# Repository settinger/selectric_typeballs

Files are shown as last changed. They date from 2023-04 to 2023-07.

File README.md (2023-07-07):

# How to make your own Selectric Typeballs

## March 31, 2023

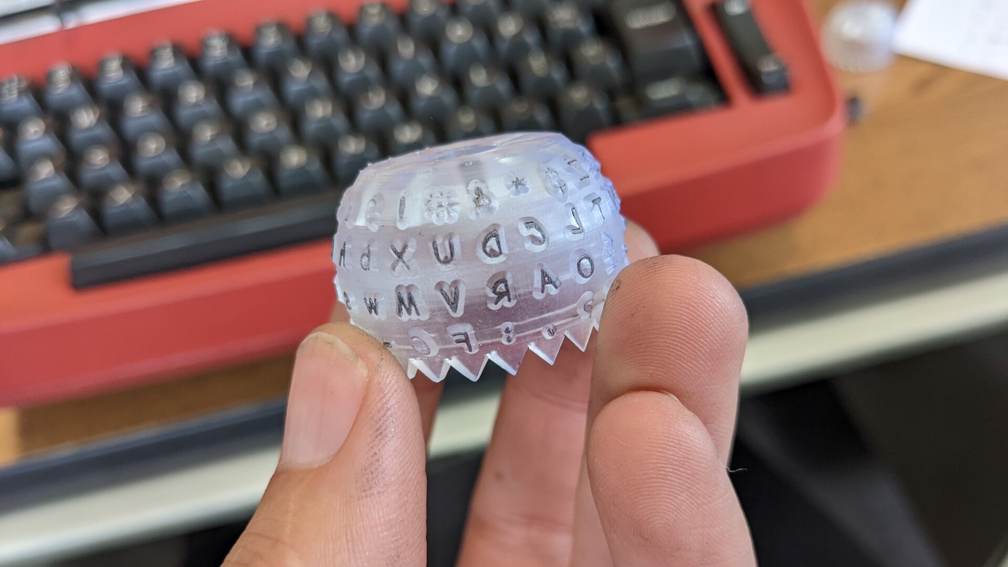
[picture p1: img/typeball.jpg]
A 3D printed typeball for the IBM Selectric. The font is Comic Sans. There is ink on most of the letters.

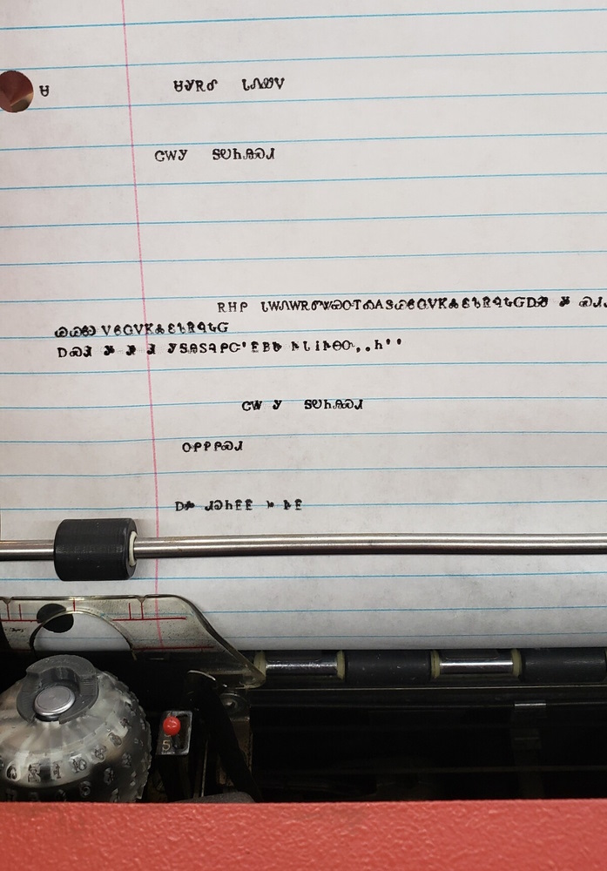
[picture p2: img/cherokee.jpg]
A sheet of lined paper in a typewriter with several lines of Cherokee text; the 3d printed typeball that made the text is visible in the lower left.


# Update: July 7 2023: YOU PROBABLY SHOULDN'T PRINT THIS!

Update, July 7 2023: [Dave Hayden](https://selectricrescue.org/) took the resin-printed typeball concept and [improved on it greatly](https://selectricrescue.org/balls/SelectricElement88.scad). I'm extremely grateful that he took on all the hard work of iteratively going through and dialing in the perfect values to make a functional ball, and I'm pleased to think I contributed in some way to his achievements.

The original README continues below.

-----------------------------------------

The [IBM Selectric typewriter](https://www.ibm.com/ibm/history/ibm100/us/en/icons/selectric/) uses an instantly-recognizable "ball" of type instead of a fanned-out array of arms like a conventional typewriter. These typeballs could be swapped out, meaning you could easily write documents with different fonts, font sizes, special characters, or different writing systems altogether.

IBM and some other vendors made lots of different typeballs, but most of them are 40-50 years old and no one has been making new typeballs for a long time. 3D printing is a natural fit for making new typeballs, but most printers still don't have the ability to produce the sharp details necessary on a sufficiently-resilient material. So it's understandable that no one made a really functional 3D-printable typeball. Until now, that is!

## Warning
Please keep in mind that the spindle that the typeball sits on is fragile. Do not force a typeball onto the spindle if it does not fit, and do not attempt to salvage a print by shaving it down. The typeball can become stuck on the delicate spindle, damaging your vintage typewriter. Similarly, do not use a typeball if it is too loose and cannot be attached securely. It could fly off and damage its surroundings.

You may wish to use a small amount of sewing machine oil on the inside of your print, to help it as it spins, and to catch any resin dust that is created by the printed ball rubbing against the spindle mount.

Any damage incurred through the use of this software and its resulting typeballs are not our liability.

## How to use the code
Things you need before getting started:
* OpenSCAD
* A Python installation with the [pymeshlab](https://pypi.org/project/pymeshlab/) package

1. Open `oneletter.scad` and change lines 11 and 12, the ones that specify the font height (in millimeters) and the font name/style for OpenSCAD to use.
1. Open `selectric_generator.py` and change line 5, the one that says `PATH TO OPENSCAD = r"{something}"` so that it points to your installation of `openscad.com` (not `openscad.exe`! They are in the same folder probably, but the `.com` is meant to be run from command line, which is what we'll be doing.
1. If you want to change the characters on the balls, edit `glyph_tables.py`. This contains a multi-dimensional array of the characters as they are arrayed on the typeball, *not as they are laid out on the keyboard*. If you want to use a different character set than the standard Latin, you'll have to find a correspondence between the new set and your preexisting keyboard layout. Sorry this part may be extra-confusing.
1. Run `selectric_generator.py`. On my machine, each character takes between 1 and 30 seconds to generate, depending on their complexity. So 88 characters will take a while, be patient!

## Acknowledgements

The blank typeball is based on [1944GPW's typeball on Thingiverse](https://www.thingiverse.com/thing:4126040), which is released under a Creative Commons-Attribution license. I suspect that my project wouldn't exist if it weren't for this one. I had to change most of their typeball dimensions, and there are major issues with the way their characters are generated, but I sure as heck would have made those same errors myself, so I'm infinitely grateful for the people before me who documented their processes!

Another project that deserves a lot of credit is [The Sincerity Machine by Jesse England](jesseengland.net/project/sincerity-machine-the-comic-sans-typewriter/). Jesse is a delight and a constant source of creative inspiration for me, and it brings me great joy to watch this project evolve with him.

## EXPLAINING HOW THE GEOMETRY WORKS, BECAUSE I'M REALLY QUITE PROUD OF IT (BUT YOU CAN SKIP THIS SECTION, IT WON'T HURT MY FEELINGS)

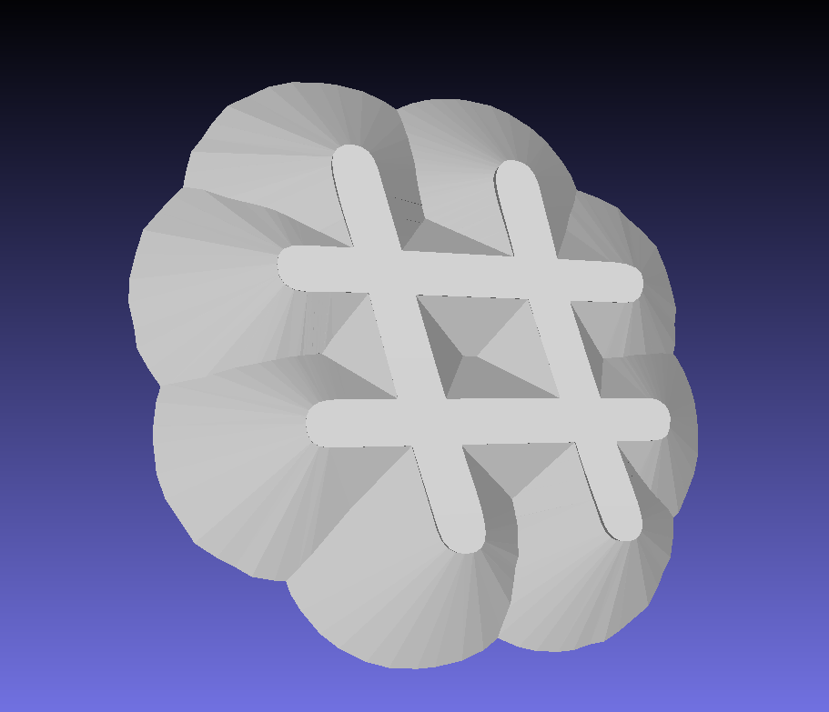
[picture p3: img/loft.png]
A Meshlab render of the octothorpe symbol with lofted edges


Getting those nice lofted edges on each glyph was not easy! I came up with a rather elaborate way that worked pretty well, but then got an excellent suggestion from Kris Slyka that works so, so much better. This is truly a community effort. I'd be very curious to hear how you would have approached it!!

The [OpenSCAD Typeball by 1944GPW](https://www.thingiverse.com/thing:4126040) attempts to loft the shapes by scaling the letterform. This was my first thought, as well, but since the letters scale around a specific point, it means the lofted sides won't all spread out evenly. Instead you get unhelpful overhangs:

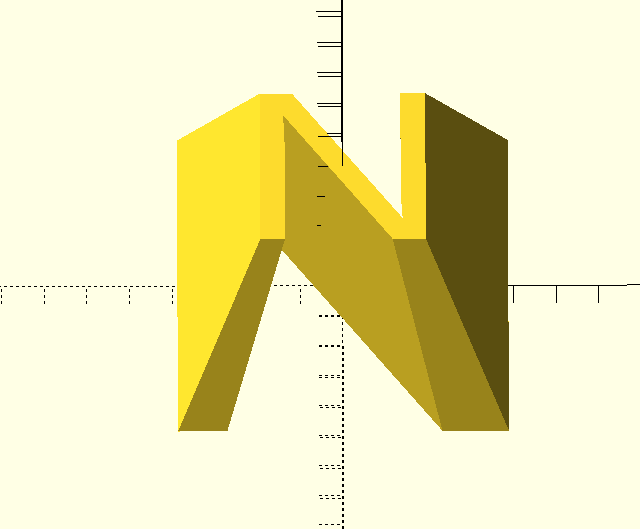
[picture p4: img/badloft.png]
An OpenSCAD render of the letter "N" with steeply slanted edges that would not print well


Instead of a scaled extrusion, we need the base to be a puffed-out offset version of the original letterform. It's not trivial to do that in an automated fashion, especially if there are small holes that will close up (like in the middle of the # character). The method I came up with uses a command-line script to extrude the letter in OpenSCAD and then displace one layer of vertices by their normal vectors. This means the vertex will always be pushed *out* away from the body of the STL.

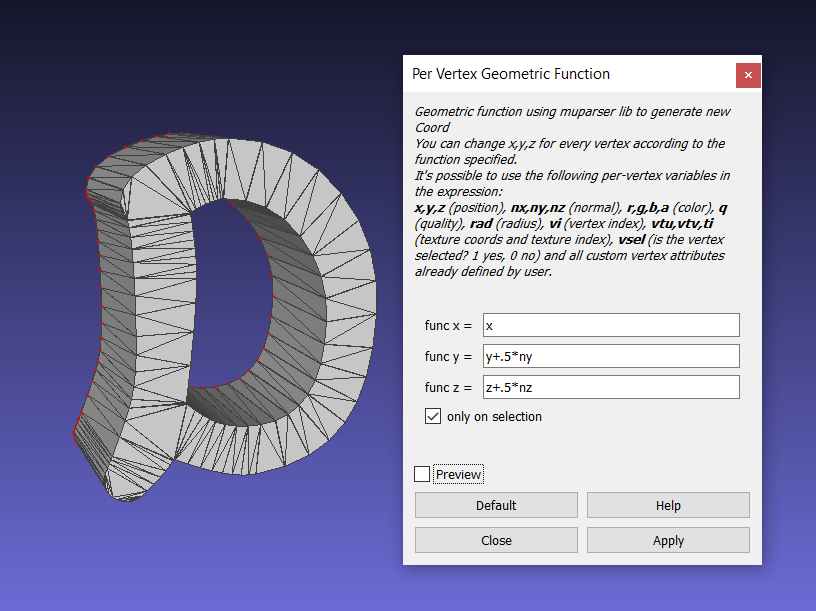
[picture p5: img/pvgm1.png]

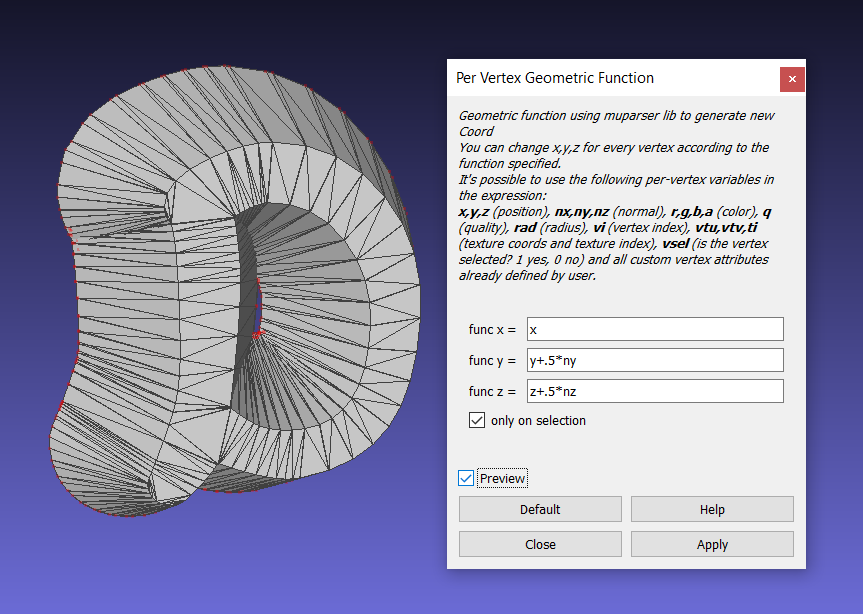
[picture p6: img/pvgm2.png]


If you look at the underside of each letter, you'll see a that this method leaves a lot of topological scars from attempts to re-mesh this self-intersecting shape. But it turned out to be pretty printable, so I released the project with this approach.

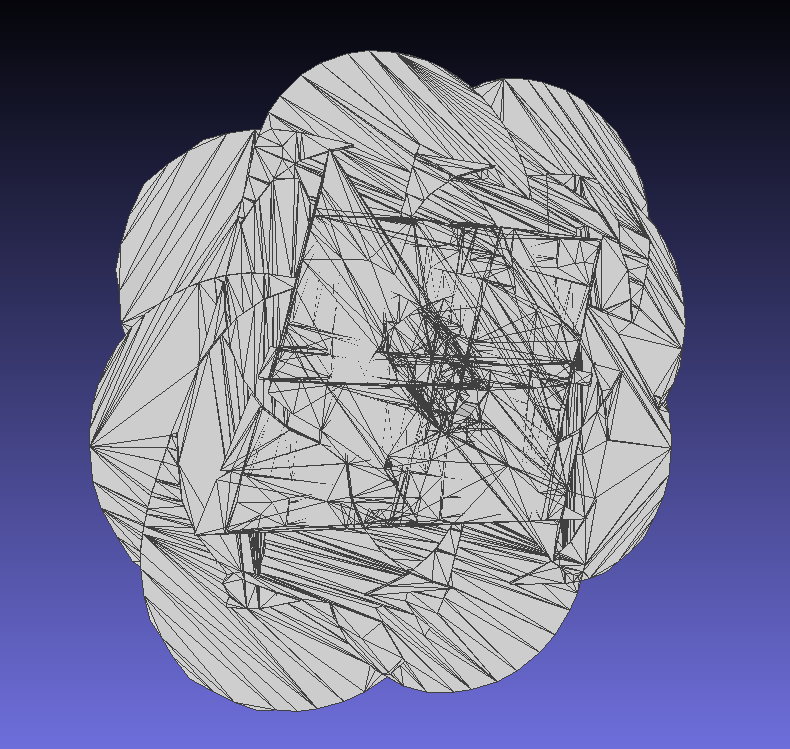
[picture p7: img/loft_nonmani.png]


After seeing the discussion about typeballs on Mastodon, Kris Slyka approached me to suggest using OpenSCAD's `minkowski()` function. It has a reputation for being agonizingly slow, and trying to generate all the glyphs at once would exhaust my PC's memory, but with the batch-script, one-letter-at-a-time method, it can work! I highly recommend getting a recent build of OpenSCAD nightly; the fast-csg setting makes `minkowski()` operations so, so much faster.

# Extra thoughts

[I put some typeballs on Printables!](https://www.printables.com/search/models?q=tag:typeball%20@settinger_263029) They are also available on Shapeways (links in the Printables descriptions) if you don't want to print them yourself.

To affix the typeball to the typewriter, you will need a bent wire or a small clip [such as this one from Dave Hayden](https://www.printables.com/model/416841-selectric-ball-clip). Thank you Dave for encouraging me to pick up the Selectric project again!

I had been testing on a not-fully-functional Selectric I, which I think was set to 12 characters per inch. Knowing characters per inch is important for joined/cursive scripts like Mongolian. It would really help if I knew how to change the writing direction, I know some Selectrics had an RTL/LTR switch...

Other right-to-left scripts to try: Thaana, N'ko

Other typeballs to try: Osage, Tifinagh, various runes, emoji, Avoiuli, um......what else?

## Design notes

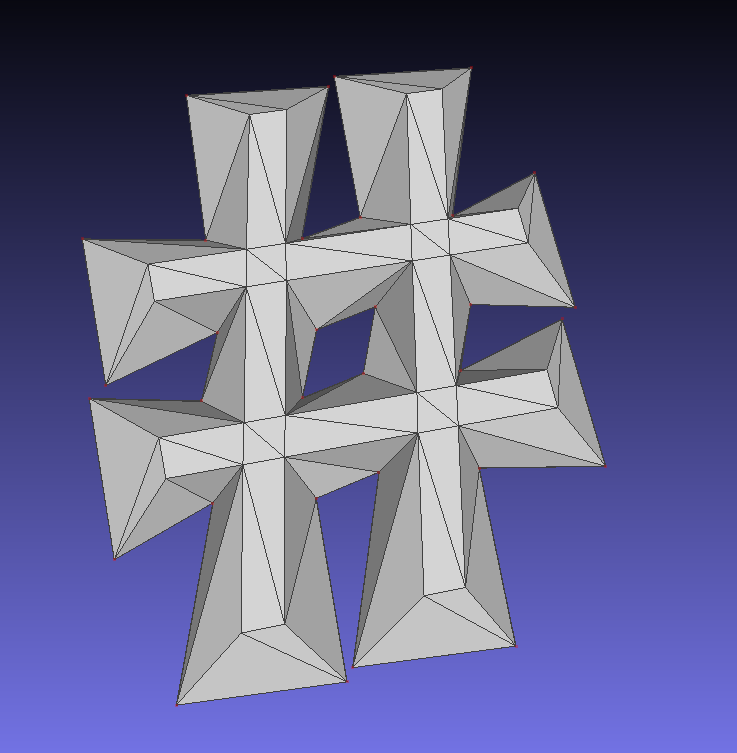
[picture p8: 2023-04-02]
img/corners1.png

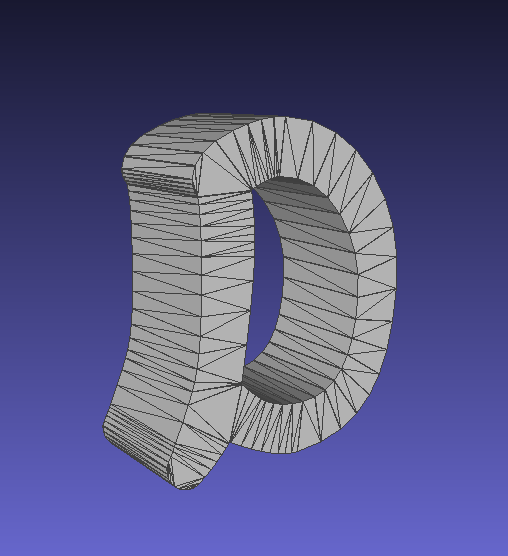
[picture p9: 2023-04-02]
img/demo1.png

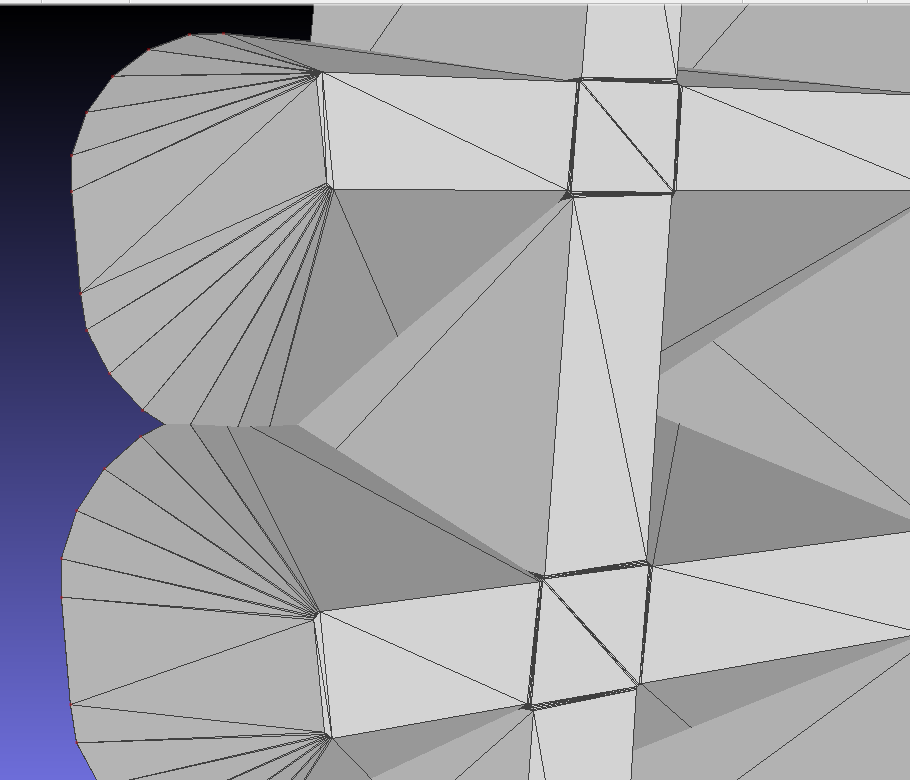
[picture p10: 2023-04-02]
img/corners2.png

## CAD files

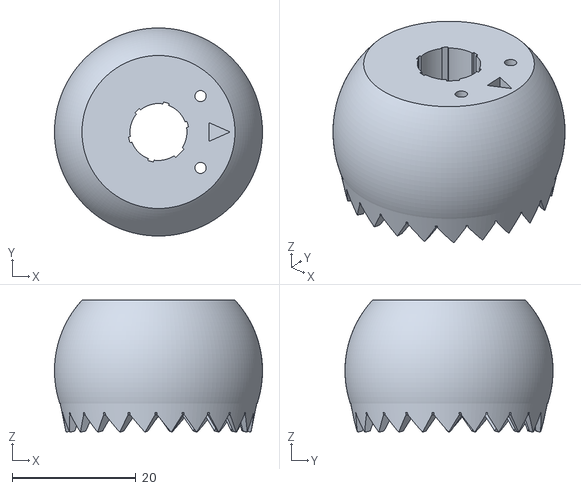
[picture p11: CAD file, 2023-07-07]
typeball_blank.STL
33.6 x 33.6 x 21.3

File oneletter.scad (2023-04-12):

// TODO: Put a preamble here

// Define some values we'll use throughout this
// Letters extend out 0.6875" from the center of the typeball
// The ball itself has a radius of around 0.6625"
// According to John Savard, the platen has a radius around 0.717" or so (http://www.quadibloc.com/comp/pro04.htm)
letterRadius = 0.6875*25.4;
ballRadius = 0.6625*25.4;
platenRadius = 0.717*25.4;

fontSize = 2.3;
myFont = "Comic Sans MS:style=Regular";

$fn=24;

codepoints=[98,99];
case = 0;
row = 0;
column = 0;
glyph = chr(codepoints);

rotate([0, 0, -180/11*column + 180*case + 5/11*180])
rotate([0, -32 + 16*row, 0])
translate([letterRadius, 0, 0])
rotate([0, 0, -90])
minkowski() {
  difference() {
    translate([0, 0.5, 0]) rotate([90, 0, 0]) linear_extrude(.55) translate([0, -fontSize/2, 0]) text(glyph, size=fontSize, halign="center", font=myFont);
    translate([0, platenRadius, 0]) rotate([0, 90, 0]) cylinder(h=20, r=platenRadius, $fn=360, center=true);
  }
  rotate([90, 0, 0]) cylinder(h=1, r1=0, r2=.9);
}

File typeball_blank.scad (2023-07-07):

// This is a reduced-complexity version of the original typeball .scad file by 1944GPW on Thingiverse
// Several constants were changed to fit my printer, your own needs may vary!


// f) sloppiness fit on spigot

UPPER_BALL_SOCKET_TOLERANCE = 0; // [ -0.3,-0.2,-0.1,0,0.1,0.2,0.3,0.4]

SLOT = true;

CLIP_SCREW_DIA = 1.8;        // [1.5,1.6,1.7,1.8,1.9,2.0,2.1,2.2,2.3]


//----------------------------------------------------------------------------------------------------------
module customizer_stopper() {}  // Stop Customiser looking at variables beyond this 

// Rendering granularity for F5 preview and F6 render. Rendering takes a LOT of time.
PREVIEW_FACETS = 40;
RENDER_FACETS = 135;

FACETS = $preview ? PREVIEW_FACETS : RENDER_FACETS;
FONT_FACETS = FACETS;
$fn = FACETS;

// Selectric II typeball sphere parameters
TYPEBALL_RAD = 0.6625*25.4;
TYPEBALL_WALL_THICKNESS = 2;
// Top face parameters
TYPEBALL_TOP_ABOVE_CENTRE = 11.4; // Flat top is this far above the sphere centre
DEL_BASE_FROM_CENTRE = 8.2;
DEL_DEPTH = 1.7;

// Detent teeth skirt parameters
TYPEBALL_SKIRT_TOP_BELOW_CENTRE = -5.33;  // Where the lower latitude of the sphere meets the top of the skirt
SKIRT_HEIGHT = 4.57;
TOOTH_PEAK_OFFSET_FROM_CENTRE = 6.1; // Lateral offset of the tilt ring detent pawl

// Parameters for the centre boss that goes onto tilt ring spigot (upper ball socket)
BOSS_INNER_RAD = 4.60 + UPPER_BALL_SOCKET_TOLERANCE;   //20190903  4.45;    // d=8.5
BOSS_OUTER_RAD = 5.65; //20190903    5.5;
BOSS_HEIGHT = 8.32; //20190914    8.69;
SLOT_ANGLE = -45;        //APPROXIMATION. TODO CHECK
SLOT_WIDTH = 1.9; //20190904    2;         //APPROXIMATION. TODO CHECK
SLOT_DEPTH = 0.3;         //APPROXIMATION. TODO CHECK
NOTCH_ANGLE = SLOT_ANGLE + 180;        //APPROXIMATION. TODO CHECK
NOTCH_WIDTH = 1.1;  // 20190904     1.5;         //APPROXIMATION. TODO CHECK
NOTCH_DEPTH = 3;//1.5;         //APPROXIMATION. TODO CHECK
NOTCH_HEIGHT = 2.2;        //APPROXIMATION. TODO CHECK  FOR NOTCH INSTEAD

// Inside reinforcement ribs
RIBS = 11;
RIB_LENGTH = 8.9;
RIB_WIDTH = 2;
RIB_HEIGHT = 3;

// Rabbit ears wire retaining clip screw hole parameters
RABBIT_EARS_CLIP_MOUNTING_SCREWS_CENTRE_TO_CENTRE = 11.6;
RABBIT_EARS_CLIP_MOUNTING_SCREWS_FROM_TILT_RING_SPIGOT = 6.8;
SCREW_BOSS_RAD = CLIP_SCREW_DIA + 0.8;   // Inside, between ribs
// Character layout
CHARACTERS_PER_LATITUDE = 22;   // For Selectric I and II. 4 x 22 = 88 characters total.

// Generate the model.
TypeBall();
// The entire typeball model proper.
module TypeBall()
{
    CorrespondenceTypeBall();
}
module CorrespondenceTypeBall()
{
    difference()
    {
        HollowBall();
        if (SLOT)
            Slot();
        Notch();
        ScrewHoles();
        Del();
    }
}

//////////////////////////////////////////////////////////////////////////////////////////////////////
// position child (a typeface letter) at global latitude and longitude on sphere of given radius
module GlobalPosition(r, latitude, longitude)
{
    x = r * cos(latitude);
    y = 0;
    z = r * sin(latitude);    
    rotate([ITALIC_BIAS, 0, longitude])
        translate([x, y, z])
            rotate([0, 90 - latitude - NORTHWARDS_ZENITH_OFFSET, 0])
                children();
}

// The unadorned ball shell with internal ribs and screw bosses
module HollowBall()
{
    //difference()
    {
        Ball();
        offset(-3)
            Ball();
    }
    Ribs();
    ScrewBosses();
}

module Ball()
{
    arbitraryRemovalBlockHeight = 20;
    // Basic ball, trimmed flat top and bottom
    difference()
    {
        sphere(r=TYPEBALL_RAD);
        translate([-50,-50, TYPEBALL_TOP_ABOVE_CENTRE])
            cube([100,100,arbitraryRemovalBlockHeight]);
        //translate([-50,-50, TYPEBALL_SKIRT_TOP_BELOW_CENTRE - arbitraryRemovalBlockHeight - 0.1])   // ball/skirt fudge factor
        translate([-50,-50, TYPEBALL_SKIRT_TOP_BELOW_CENTRE - arbitraryRemovalBlockHeight])   // ball/skirt fudge factor
            cube([100,100,arbitraryRemovalBlockHeight]);
        sphere(r=TYPEBALL_RAD - TYPEBALL_WALL_THICKNESS);
    }
    // Fill top back in
    TopFace();
    // Detent teeth skirt
    //translate([0,0,0.05]) // fudge factor overlap ball/detent teeth
        DetentTeethSkirt();
    CentreBoss();
}

//////////////////////////////////////////////////////////////////////////
//// Detent teeth around bottom of ball
module DetentTeethSkirt()
{
    foo = .48;
    SKIRT_OUTSIDE_UPPER_RAD = 16.38-foo;
    SKIRT_OUTSIDE_LOWER_RAD = 15.45-foo;
    TOOTH_TIP_THICK = 1.2; //1.5;
    // Detent teeth skirt
    difference()
    {
        translate([0,0, TYPEBALL_SKIRT_TOP_BELOW_CENTRE - SKIRT_HEIGHT])
            cylinder(r2=SKIRT_OUTSIDE_UPPER_RAD, r1=SKIRT_OUTSIDE_LOWER_RAD, h=SKIRT_HEIGHT);
        translate([0,0, TYPEBALL_SKIRT_TOP_BELOW_CENTRE - SKIRT_HEIGHT])
            cylinder(r2=SKIRT_OUTSIDE_UPPER_RAD - TYPEBALL_WALL_THICKNESS, r1=SKIRT_OUTSIDE_LOWER_RAD + TOOTH_TIP_THICK - TYPEBALL_WALL_THICKNESS, h=SKIRT_HEIGHT);        
        translate([0,0, TYPEBALL_SKIRT_TOP_BELOW_CENTRE - SKIRT_HEIGHT])
            DetentTeeth();
    }
}

// Ring of detent teeth in skirt
module DetentTeeth()
{
    segment = 360 / CHARACTERS_PER_LATITUDE;
    half_tooth = 0;     //segment / 2;
    for (i=[0:CHARACTERS_PER_LATITUDE - 1])
        rotate([0, 0, segment * i + half_tooth])
            Tooth();
}

module Tooth()
{
    translate([0, TOOTH_PEAK_OFFSET_FROM_CENTRE, 0])
        rotate([180, -90, 0])
        {
            linear_extrude(30)
            {
                polygon(points=[[3,0], [0,1.9], [-1,1.9], [-1,-1.9], [0,-1.9]]);
                translate([0, -.15, 0])
                    square([3.1, .3]);
            }
        }
}

//////////////////////////////////////////////////////////////////////////
//// Flat top of typeball, punch tilt ring spigot hole through and subtract del triangle
module TopFace()
{
    // Fill top back in, after the inside sphere was subtracted before this fn was called
    difference()
    {
        translate([0, 0, TYPEBALL_TOP_ABOVE_CENTRE - TYPEBALL_WALL_THICKNESS])
            cylinder(r=11.8, h=TYPEBALL_WALL_THICKNESS);
        translate([0, 0, TYPEBALL_TOP_ABOVE_CENTRE - TYPEBALL_WALL_THICKNESS])
            cylinder(r=BOSS_INNER_RAD,h=TYPEBALL_WALL_THICKNESS*2);
        Del();
    }   
}

// Alignment marker triangle on top face
module Del()
{
    translate([DEL_BASE_FROM_CENTRE, 0, TYPEBALL_TOP_ABOVE_CENTRE - DEL_DEPTH])
        color("white")  // TODO red triangle for Composer typeball
        linear_extrude(DEL_DEPTH)
            polygon(points=[[3.4,0],[0,1.5],[0,-1.5]]);
}

// Emboss the font name (truncated) onto top face, and also an estimate of font pitch

// Clean up any base girth bits of T0-ring characters projecting above top face
module TrimTop()
{
    translate([-50,-50, TYPEBALL_TOP_ABOVE_CENTRE])
        cube([100,100,20]);
}

//////////////////////////////////////////////////////////////////////////
// Tilt ring boss assembly
module CentreBoss()
{
    translate([0,0, TYPEBALL_TOP_ABOVE_CENTRE - BOSS_HEIGHT])
        difference()
        {
            cylinder(r=BOSS_OUTER_RAD, h=BOSS_HEIGHT);
            cylinder(r=BOSS_INNER_RAD, h=BOSS_HEIGHT);
        }    
}

// The full-length slot in the tilt ring boss at the half past one o'clock position
module Slot()
{
    // big slot
    rotate([0, 0, SLOT_ANGLE])
        translate([0, -SLOT_WIDTH/2, 0])
            cube([SLOT_DEPTH + BOSS_INNER_RAD, SLOT_WIDTH, 40]);

    // 5 more minor slots, to reduce friction when inserting or removing the typeball.
    // these slots are present on some official IBM balls, but not most. Perhaps it was a later refinement.
    rotate([0, 0, SLOT_ANGLE + 60])
        translate([0, -SLOT_WIDTH/4, 0])
            cube([SLOT_DEPTH + BOSS_INNER_RAD, SLOT_WIDTH / 2, 40]);

    rotate([0, 0, SLOT_ANGLE + 120])
        translate([0, -SLOT_WIDTH/4, 0])
            cube([SLOT_DEPTH + BOSS_INNER_RAD, SLOT_WIDTH / 2, 40]);

    rotate([0, 0, SLOT_ANGLE + 180])
        translate([0, -SLOT_WIDTH/4, 0])
            cube([SLOT_DEPTH + BOSS_INNER_RAD, SLOT_WIDTH / 2, 40]);

    rotate([0, 0, SLOT_ANGLE + 240])
        translate([0, -SLOT_WIDTH/4, 0])
            cube([SLOT_DEPTH + BOSS_INNER_RAD, SLOT_WIDTH / 2, 40]);

    rotate([0, 0, SLOT_ANGLE + 300])
        translate([0, -SLOT_WIDTH/4, 0])
            cube([SLOT_DEPTH + BOSS_INNER_RAD, SLOT_WIDTH / 2, 40]);
}

// The partial-length slot in the tilt ring boss at the half past seven o'clock position
module Notch()
{
    rotate([0, 0, NOTCH_ANGLE])
        translate([0, -NOTCH_WIDTH/2, TYPEBALL_TOP_ABOVE_CENTRE - BOSS_HEIGHT])
            cube([NOTCH_DEPTH + BOSS_INNER_RAD, NOTCH_WIDTH, NOTCH_HEIGHT]);
}
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

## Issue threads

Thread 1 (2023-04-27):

Post source for the blank keyball

cculpepper, 2023-04-27:
Hello! This is a fantastic project, thank you!

Could you post the source for the blank typeball? Particularly, it looks like the hole is too small, and rotation locking peg is too large for the print (Granted both of these could be my print or my cleanup, but maybe not!)

I'd use the "parent" project, but you say you made a bunch of changes to it, and I'd rather not edit the .stl if possible.

Thank you!
Chris

settinger, 2023-05-02:
Hi hello I have not forgotten about this! I am (figuratively) juggling too many things but you are absolutely right that the .scad file for the blank ball needs to be added soon!

Hubcapp, 2023-07-04:
Confirmed the hole is too small to fit.

settinger, 2023-07-06:
The typeball SCAD source is included now, apologies again for not providing that sooner.

A couple people started to make excellent improvements of their own; I will try reaching out to get a more useful, more developed typeball generator available to everyone, but it's would most likely be a separate project somewhere else, not in this repo. I'm struggling to find a reason to maintain this version of the typeball generator, especially since I still can't find a functional Selectric to validate parts on.

Closed 2023-07-06.

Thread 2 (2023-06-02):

Issues with generator script on Windows 10

Niosquare, 2023-06-02:
Hello! I am running this on Windows, with all the pre-requisites met. I am running this on Python 3.11.3. I know nothing about Python, so I did try to fix some stuff through solutions I found online. The first issue I had was with line 39, where I was met with the following:

`Generating glyph 1...
Traceback (most recent call last):
  File "C:\selectric_typeballs-main\selectric_generator.py", line 39, in <module>
    subprocess.run(cmd)
  File "C:\Users\chris\AppData\Local\Programs\Python\Python311\Lib\subprocess.py", line 548, in run
    with Popen(*popenargs, **kwargs) as process:
  File "C:\Users\chris\AppData\Local\Programs\Python\Python311\Lib\subprocess.py", line 1024, in __init__
    self._execute_child(args, executable, preexec_fn, close_fds,
  File "C:\Users\chris\AppData\Local\Programs\Python\Python311\Lib\subprocess.py", line 1509, in _execute_child
    hp, ht, pid, tid = _winapi.CreateProcess(executable, args,
FileNotFoundError: [WinError 2] The system cannot find the file specified`

I was able to fix this, by adding this to line 40:
` subprocess.run(cmd, shell=True)`
Then, after that, I encountered the following when trying to run it:
`Generating glyph 1...
Traceback (most recent call last):
  File "F:\Downloads (mom)\selectric_typeballs-main\selectric_typeballs-main\selectric_generator.py", line 40, in <module>
    mainMeshSet.load_new_mesh(filename)
pymeshlab.pmeshlab.PyMeshLabException: File does not exists: ballparts/0-0-0.STL`

Is there anything I'm doing wrong? Hope I can solve this. Very awesome project you've worked on here, I can't wait to try it on my machine.

settinger, 2023-06-02:
Hi, thanks for trying out the repo! In the folder where the main .py file
is, can you try creating an empty directory named `ballparts`? I think
Python is trying to create a file in that directory, but it's unable to
create the directory itself.

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

Niosquare, 2023-06-03:
Thank you for the response! The script is able to create the "ballparts" folder on its own, I deleted it, ran the script again, and it again made the folder but met with same error. I created it on my own one time, but to no avail. I think the .stl file mentioned in the error message, _0-0-0.STL_, corresponds to a character on the typeball, right? Thank you again for helping!

settinger, 2023-06-03:
I see, so there's still some issue preventing it from generating and saving
the file 0-0-0.STL (which would be the character in the 0th column, 0th
row, and (iirc) lowercase). I'm traveling at the moment, wish I could help
you more but please keep me posted if you observe anything else!

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

Hubcapp, 2023-07-04:
Works fine for me. This looks like a windows permissions error (you may need to move the project folder somewhere else, e.g. to C:\Users\YourName\Documents\selectric_typeballs).

Niosquare, 2023-07-19:
Got it to work! Thank you so much guys! The work you've been doing on this project is amazing, it breathes some new life into the Selectric. Currently rendering Quadrivium NF!

P.S I don't have a 3D printer to print these with, unfortunately. Is there any service I can use to outsource the printing? Thanks again!

Closed 2023-07-19.

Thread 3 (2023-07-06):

Dimensions of blank ball are wrong, may damage typewriter

Hubcapp, 2023-07-06:
Hi, sorry to be alarmist, I love the idea of this project, however, it is currently unusable and dangerous due to the included STL file for the blank typeball having incorrect dimensions.

The dimensions are close enough that I was fooled into shaving it down a little and pressing it onto the spindle. The typeball I printed then went on, but it did not come off. Removing it as gently as I could was too violent of a force for the fragile head, and it has now put my Selectric II slightly out of alignment. This is perhaps a boneheaded move on my part, but I found evidence in <a href="https://www.youtube.com/watch?v=BLuB_FLSpTY">this repair video's youtube comments</a> that I am not the only idiot who excitedly pressed their newly printed slightly-too-small 3d typeball onto the spindle.

I believe that addressing issue #1 should be high priority for you, since as is, the hosted files supplied on Printables, as well as the blank STL included in this repo, will continue to disappoint, and damage the vintage equipment of those who actually try to print and use them.

settinger, 2023-07-06:
Thanks for the info, I'll pull down the Shapeways links and put a warning on the Printables ones. I certainly don't want to damage any typewriters!

Can you tell me about the printer and resin you used to print the typeball? Was typeball height wrong, or the diameter of the spindle hole, or something else? I'll get issue #1 resolved now, though the parameters in the source file are still tuned for my printer and my resin (which apparently makes it too tight for others to print).

Best of luck re-aligning your Selectric!

Hubcapp, 2023-07-06:
Hi, thanks for the quick response. 🙂

I used an Elegoo Saturn 2 resin printer with Siraya tech blu engineering resin. This resin is harder than other resins & ideal for mechanical applications such as 3D printed selectric type element. 🙂

My printing profile is calibrated, you can see a successful "Towns" print in the picture attached. You should definitely consider calibrating your print profile to an existing standard model instead of adjusting the 3D model to match.

In the moments before I tried to remove the ball, I was impressed that the printer does in fact have enough resolution to successfully type a very convincing floppy disk icon.

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

In researching realignment, I found out that there are over 800 different adjustments, and that an untrained person like myself can very quickly get it even worse out of alignment. I'll have to wait until I can get it back to a professional, but until then I have come to terms with the fact that my unit just has a bit of a wonky personality now.

settinger, 2023-07-06:
The printer I used is a Formlabs 3B+ that is mostly used for validating biomedical devices; I assure you it is well calibrated :)

The typewriter that I tested on initially was a Model I Selectric, perhaps the spindle is a slightly different dimension? The fit was very good but not all the keys work on that machine so I can't use it consistently.

Hubcapp, 2023-07-06:
Elements for I & II are the same, I think it should be the same dimensions on the spindle. 🤔

Hubcapp, 2023-07-06:
I took a couple measurements, ⬇️👍📏

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

Hubcapp, 2023-07-07:
Thanks for posting the typeball_blank.scad source code. The 0.362 inch diameter measurement I took of that IBM type element, it looks like the radius should be about 4.60 mm, but BOSS_INNER_RAD is defined as 4.30 mm.

Hubcapp, 2023-07-07:
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

It's actually maybe more complicated? The .362 is from dedent to dedent. There are 6 small dedents on the inside of the boss which are not actually modeled at all in the typeball and may have some use. I'm going to try just a larger radius but will report back on that.

settinger, 2023-07-07:
Thank you for all the measurements and corrections in the PR! Dave Hayden of selectricrescue.org made some major improvements and created a version that works quite well in just OpenSCAD, without relying on external tools. You can get a copy of it here: https://selectricrescue.org/balls/SelectricElement88.scad

Dave also suggests:
> As for messing up the alignment, my guess is that they rotated or tilted the element which put slack in the corresponding tape and it fell off one of its pulleys. It's an easy fix, you tilt or rotate it again and guide the tape back onto the pulley and gently release the ball back to its neutral position. If that's what happened hopefully they didn't use it too much with the tape off and kink it up.

Closed 2023-07-07.

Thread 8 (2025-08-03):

Added IBM Selectric-III 96-char typeface element support

joshshapiro, 2025-08-03:
Howdy! I've reworked Dave Hayden's redesign from this project to add Selectric-III 96-char ball support. I don't have a resin printer, but the configurability is there; it's ready for testing.

https://github.com/joshshapiro/Selectric_III_typeballs

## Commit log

2023-04-01 Preparing for release
    [oneletter.scad, typeball_blank.STL]
2023-04-02 Improve readme and blank ball
    [typeball_blank.STL]
2023-04-11 Better manifoldness with minkowski!
    [oneletter.scad]
2023-04-12 Widened the base of each letter a bit
    [oneletter.scad]
2023-07-06 Add typeball scad source
    [typeball_blank.scad]
2023-07-07 looser fitment onto spindle, model inner slots found on some IBM typeballs that reduce friction, add Warning to README.md
    [typeball_blank.STL, typeball_blank.scad]
